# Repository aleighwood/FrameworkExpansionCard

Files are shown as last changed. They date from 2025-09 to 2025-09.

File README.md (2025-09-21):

# FrameworkExpansionCard

This framework expansion card measures ambient C02 concentration, temperature and humidity. It can be used on any computer with a USBC port. Currently, you can view the sensor readings using your preferred serial interface. In the future I will make a nice UI - any maybe automated high C02 level warnings. 

You will need to install the appropriate drivers for the CP2102 chip. Other ICs included an ATMega328 and Sensirion SCD40.

Unfortunately the size of the Sensirion SCD40 IC prohibits the device from fully fitting into the Framework expansion card bay. In the future I will use the newly released Sensirion STCC4 sensor, allowing the device to fit snugly into the expansion card port.

This is a project that I did under the supervision of Professor Mikhelson at Northwestern University (Chicago).

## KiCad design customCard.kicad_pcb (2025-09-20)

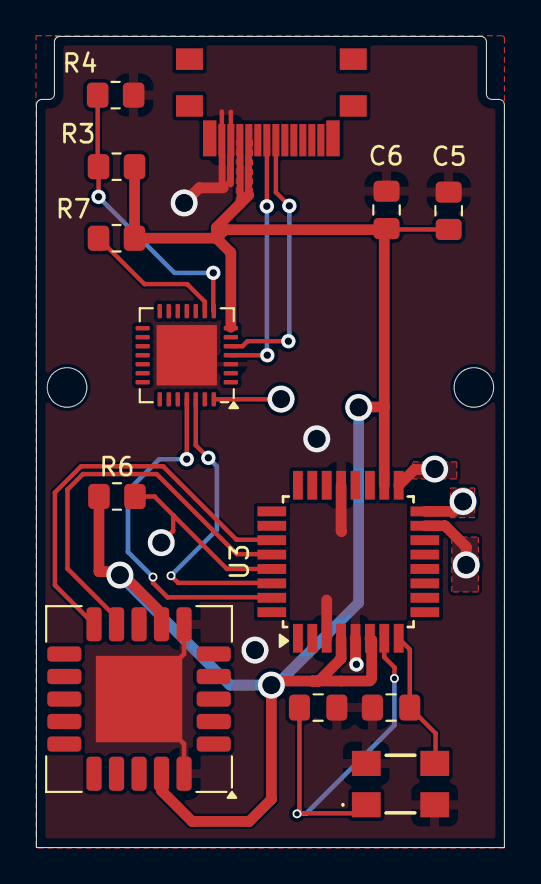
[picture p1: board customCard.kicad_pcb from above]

Board: 2 copper layers, 26.0 x 45.1 mm, 15 parts (0 on the bottom side), 13 nets.

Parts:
C1: 830030819
C3, C4: 18p; C_0805_2012Metric_Pad1.18x1.45mm_HandSolder
C5: 4.7u; C_0805_2012Metric_Pad1.18x1.45mm_HandSolder
C6: 0.1u; C_0805_2012Metric_Pad1.18x1.45mm_HandSolder
H1, H2: MountingHole; MountingHole_2.2mm_M2
R3: 22.1k; R_0805_2012Metric_Pad1.20x1.40mm_HandSolder
R4: 47.5k; R_0805_2012Metric_Pad1.20x1.40mm_HandSolder
R6: 10k; R_0805_2012Metric_Pad1.20x1.40mm_HandSolder
R7: 1k; R_0805_2012Metric_Pad1.20x1.40mm_HandSolder
U1: framework_adafruit_USBC_connector
U3: ATmega328-A; TQFP-32_7x7mm_P0.8mm
U4: CP2102N-Axx-xQFN28; QFN-28-1EP_5x5mm_P0.5mm_EP3.35x3.35mm
U5: SCD40-D-R2; Sensirion_SCD4x-1EP_10.1x10.1mm_P1.25mm_EP4.8x4.8mm

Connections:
5V_bus: C5.1, C6.1, R3.1, R6.1, R7.1, U1.A4(VBUS) (VBUS), U1.B9(VBUS) (VBUS), U3.4 (VCC), U3.6 (VCC), U3.18 (AVCC), U4.7 (VREGIN), U5.7 (VDD), U5.19 (VDD)
/ATMega RX: U3.30 (PD0), U4.26 (TXD)
/ATMega TX: U3.31 (PD1), U4.25 (RXD)
GND: C1.2 (GND_&_LID_1), C1.4 (GND_&_LID_2), C3.2, C4.2, C5.2, C6.2, R4.2, U1.A1(GND) (GND), U1.B12(GND) (GND), U3.3 (GND), U3.5 (GND), U3.21 (GND), U4.3 (GND), U4.29 (GND), U5.6 (GND), U5.20 (GND), U5.21 (GND)
unnamed: C1.1 (CRYSTAL_1), C3.1, U3.7 (XTAL1/PB6)
unnamed: C1.3 (CRYSTAL_2), C4.1, U3.8 (XTAL2/PB7)
unnamed: U1.A6(D+) (D+), U4.4 (D+)
unnamed: U1.A7(D-) (D-), U4.5 (D-)
unnamed: U3.27 (PC4), U5.10 (SDA)
unnamed: U3.28 (PC5), U5.9 (SCL)
unnamed: R6.2, U3.29 (~RESET/PC6)
unnamed: R3.2, R4.1, U4.8 (VBUS)
unnamed: R7.2, U4.9 (~RST)
